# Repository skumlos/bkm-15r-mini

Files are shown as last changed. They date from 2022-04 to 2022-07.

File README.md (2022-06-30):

BKM-15R-mini, an alternative to the Sony BKM-15R controller for your BVM-A series monitor.

A small PCB that connects to an ESP32 Devkit V1 and an ENC28J60 module.

The ESP32 module should be the 30-pin "Devkit V1" which seems pretty common. Note that an 36-pin version also exists, the
"original" Doit ESP32 Devkit V1", this version needs some "hacking" to work.

The ENC28J60 module exists in many versions. The one designed in here, is the 12-pin 5V version, sometimes referred to as "the large" version.
It should run on 5V and have 12 pins (apparently a very close version with 10 pins running straight on 3.3V also exists).

The ESP32 should be loaded with the code from here: https://github.com/skumlos/bkm-15rduino

The "Disable WiFi" switch, disables wifi... I like hard switches for stuff like this.
It's handy if you just want the physical keys (you could comment out all WiFi stuff from the code also of course...).

Press the FORCE_SETUP switch while pressing the RESET switch, to make the software go into configuration mode for WiFi setup and such.

Use a crossed ethernet cable or a switch between this and the BVM-A.

The ESP32 footprint and library symbol is originally by David Kleymann (https://github.com/davidkleymann/doit-esp32-devkit-kicad).
I modified it to fit the seemingly more common 30 pin version of the ESP32 Devkit V1.

3D printable case on thingiverse.com

(2022) Martin Hejnfelt (martin@hejnfelt.com)
www.immerhax.com

This work is free. You can redistribute it and/or modify it under the
terms of the Do What The Fuck You Want To Public License, Version 2,
as published by Sam Hocevar. See the LICENSE file for more details.

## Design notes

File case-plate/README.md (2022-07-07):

Top PCB for BKM-15R-mini shell/case

A small PCB that sits on top of the BKM-15R-mini to allow for labels and such. Should be made in 1.6mm substrate.

Designed by RetroUpgrades (www.retroupgrades.co.uk)

This work is free. You can redistribute it and/or modify it under the
terms of the Do What The Fuck You Want To Public License, Version 2,
as published by Sam Hocevar. See the LICENSE file for more details.

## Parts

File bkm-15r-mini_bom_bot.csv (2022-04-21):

Comment | Designator | Footprint | LCSC Part #
TL-1240-NO_LED | SW101 SW104 SW107 SW102 SW103 SW105 SW106 SW108 SW109 SW112 SW111 SW110 SW201 SW202 SW203 SW204 SW205

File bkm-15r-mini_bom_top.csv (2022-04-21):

Comment | Designator | Footprint | LCSC Part #
74HC14 | U101 U102 U201 | TSSOP-14 | C6066
10K | R101 R104 R107 R110 R113 R116 R102 R105 R103 R106 R108 R111 R109 R112 R114 R117 R115 R118 R121 R124 R120 R123 R119 R122 R201 R203 R202 R204 R205 R207 R206 R208 R209 R210 | 0603 | C98220
10nF | C101 C104 C107 C102 C103 C105 C106 C108 C109 C112 C111 C110 C201 C202 C203 C204 C205 | 0603 | C115056
100nF | C113 C114 C206 | 0603 | C14663
ENC28J60 | J301
SW_ForceSetup | SW301 | SMD | C388883
SW_Reset | SW302 | SMD | C388883
OS102011MA1QN1C | SW303
DOIT-ESP32-DEVKIT-V1_30PIN | U301

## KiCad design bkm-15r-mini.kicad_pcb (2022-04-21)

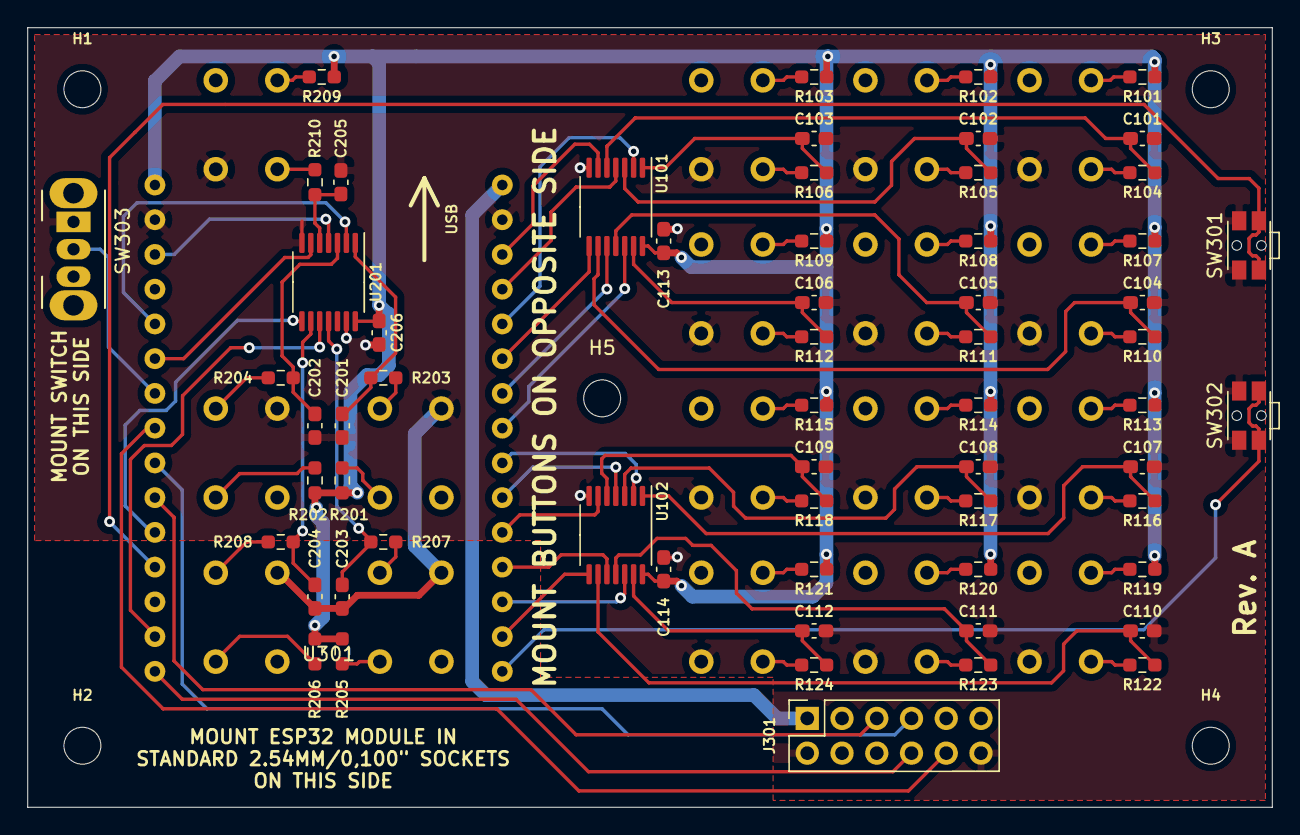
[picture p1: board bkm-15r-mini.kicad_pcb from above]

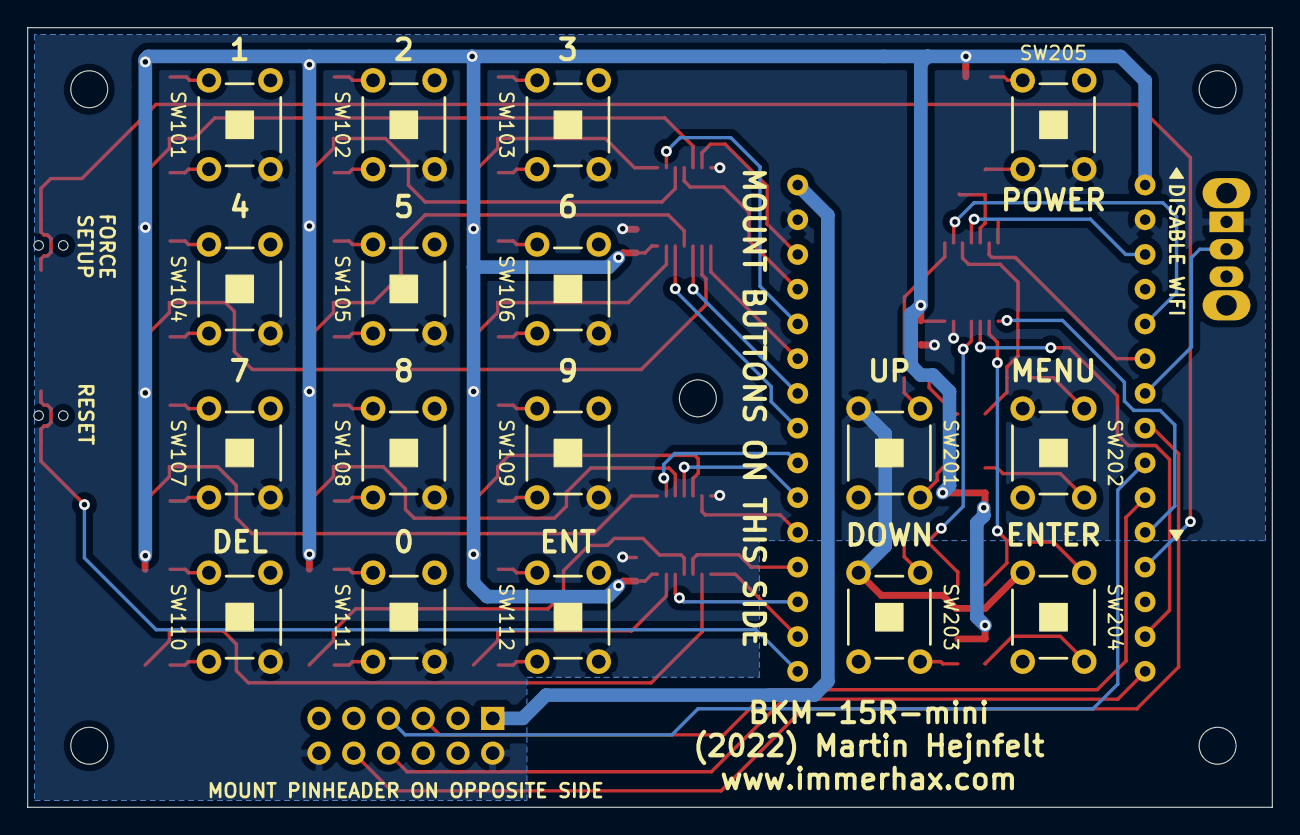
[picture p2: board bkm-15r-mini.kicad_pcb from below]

Board: 2 copper layers, 91.0 x 57.0 mm, 84 parts (17 on the bottom side), 78 nets.

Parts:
C101, C102, C103, C104, C105, C106, C107, C108, C109, C110, C111, C112, C201, C202, C203, C204, C205: 10nF; C_0603_1608Metric_Pad1.08x0.95mm_HandSolder
C113, C114, C206: 100nF; C_0603_1608Metric_Pad1.08x0.95mm_HandSolder
H1, H2, H3, H4, H5: MountingHole; MountingHole_2.7mm_M2.5
J301: ENC28J60; PinSocket_2x06_P2.54mm_Vertical
R101, R102, R103, R104, R105, R106, R107, R108, R109, R110, R111, R112, R113, R114, R115, R116, R117, R118, R119, R120, R121, R122, R123, R124, R201, R202, R203, R204, R205, R206, R207, R208, R209, R210: 10K; R_0603_1608Metric_Pad0.98x0.95mm_HandSolder
SW101, SW102, SW103, SW104, SW105, SW106, SW107, SW108, SW109, SW110, SW111, SW112, SW201, SW202, SW203, SW204, SW205: TL-1240-NO_LED
SW301: SW_ForceSetup; SW_SPST_EVQP7C
SW302: SW_Reset; SW_SPST_EVQP7C
SW303: OS102011MA1QN1C; SW_CuK_OS102011MA1QN1_SPDT_Angled
U101, U102, U201: 74HC14; TSSOP-14_4.4x5mm_P0.65mm
U301: DOIT-ESP32-DEVKIT-V1_30PIN; ESP32-DOIT-DEVKIT_30PIN

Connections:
+3V3: C113.2, C114.2, C206.2, R101.1, R102.1, R103.1, R107.1, R108.1, R109.1, R113.1, R114.1, R115.1, R119.1, R120.1, R121.1, R201.1, R202.1, R205.1, R206.1, R209.1, U101.14, U102.14, U201.14, U301.22
+5V: J301.1, U301.15
CS: J301.10, U301.29
DISABLE_WIFI: SW303.2, U301.28
FORCE_SETUP: SW301.2, U301.33
GND: C101.2, C102.2, C103.2, C104.2, C105.2, C106.2, C107.2, C108.2, C109.2, C110.2, C111.2, C112.2, C113.1, C114.1, C201.2, C202.2, C203.2, C204.2, C205.2, C206.1, J301.2, J301.12, SW101.3, SW102.3, SW103.3, SW104.3, SW105.3, SW106.3, SW107.3, SW108.3, SW109.3, SW110.3, SW111.3, SW112.3, SW201.3, SW202.3, SW203.3, SW204.3, SW205.3, SW301.1, SW302.1, SW303.1, U101.7, U102.7, U201.7, U201.13, U301.14, U301.23
INPUT_KEY0: U102.10, U301.4
INPUT_KEY1: U101.6, U301.13
INPUT_KEY2: U101.4, U301.12
INPUT_KEY3: U101.2, U301.11
INPUT_KEY4: U101.8, U301.10
INPUT_KEY5: U101.10, U301.9
INPUT_KEY6: U101.12, U301.8
INPUT_KEY7: U102.2, U301.7
INPUT_KEY8: U102.4, U301.6
INPUT_KEY9: U102.6, U301.5
INPUT_KEY_DEL: U102.8, U301.2
INPUT_KEY_ENT: U102.12, U301.3
KEY_POWER: U201.6, U301.27
NAV_KEY_DOWN: U201.10, U301.35
NAV_KEY_ENTER: U201.8, U301.32
NAV_KEY_MENU: U201.4, U301.24
NAV_KEY_UP: U201.2, U301.26
unnamed: C101.1, R104.1, U101.5
unnamed: C102.1, R105.1, U101.3
unnamed: C103.1, R106.1, U101.1
unnamed: C104.1, R110.1, U101.9
unnamed: C105.1, R111.1, U101.11
unnamed: C106.1, R112.1, U101.13
unnamed: C107.1, R116.1, U102.1
unnamed: C108.1, R117.1, U102.3
unnamed: C109.1, R118.1, U102.5
unnamed: C110.1, R122.1, U102.9
unnamed: C111.1, R123.1, U102.11
unnamed: C112.1, R124.1, U102.13
unnamed: C201.1, R203.1, U201.1
unnamed: C202.1, R204.1, U201.3
unnamed: C203.1, R207.1, U201.11
unnamed: C204.1, R208.1, U201.9
unnamed: C205.1, R210.1, U201.5
unnamed: R101.2, SW101.2
unnamed: R102.2, SW102.2
unnamed: R103.2, SW103.2
unnamed: R104.2, SW101.1
unnamed: R105.2, SW102.1
unnamed: R106.2, SW103.1
unnamed: R107.2, SW104.2
unnamed: R108.2, SW105.2
unnamed: R109.2, SW106.2
unnamed: R110.2, SW104.1
unnamed: R111.2, SW105.1
unnamed: R112.2, SW106.1
unnamed: R113.2, SW107.2
unnamed: R114.2, SW108.2
unnamed: R115.2, SW109.2
unnamed: R116.2, SW107.1
unnamed: R117.2, SW108.1
unnamed: R118.2, SW109.1
unnamed: R119.2, SW110.2
unnamed: R120.2, SW111.2
unnamed: R121.2, SW112.2
unnamed: R122.2, SW110.1
unnamed: R123.2, SW111.1
unnamed: R124.2, SW112.1
unnamed: R201.2, SW201.2
unnamed: R202.2, SW202.2
unnamed: R203.2, SW201.1
unnamed: R204.2, SW202.1
unnamed: R205.2, SW203.2
unnamed: R206.2, SW204.2
unnamed: R207.2, SW203.1
unnamed: R208.2, SW204.1
unnamed: R209.2, SW205.2
unnamed: R210.2, SW205.1
RESET: SW302.2, U301.1
SCK: J301.7, U301.30
SO: J301.5, U301.31
ST: J301.8, U301.36

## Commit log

2022-04-07 Add Rev. A plot
    [bkm-15r-mini-B_Cu.gbr, bkm-15r-mini-B_Mask.gbr, bkm-15r-mini-B_Paste.gbr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]
2022-04-21 Add JLCPCB assembly stuff, update plots
    [InputKeys.sch, MCU_LAN.sch, Navigation_Power.sch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]
2022-04-21 Forgot to save :D
    [bkm-15r-mini.kicad_pcb]
2022-07-07 Added top plate by RetroUpgrades
    [bkm-15r-mini-plate.kicad_pcb]
